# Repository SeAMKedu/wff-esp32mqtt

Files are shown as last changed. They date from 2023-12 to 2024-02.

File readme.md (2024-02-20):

[seamk_logo]:       /img/seamk_logo.svg
[epliitto_logo]:    /img/epliitto_logo.jpg
[eakr_eu_logo]:     /img/eakr_eu_logo.jpg



# Analogia signaalit pilveen

Ruokalaboratorion homogenisaattorissa on valmiit liitännät, joista voi lukea 4-20mA signaalin paineantureista. Tässä repositoryssä on kuvattu ESP32 pohjainen lähetin, joka osaa lukea nämä signaalit ja lähettää ne edelleen MQTT viesteinä eteenpäin. 

## Piirilevy

PCB kansiosta löytyy KiCAD piirustukset sovittimesta, johon voi laittaa ESP32 Dev Kitin kiinni sekä kytkeä 24V virran ja kaksi mA-signaalia. HUOM! Tämä on laajempaa jakelua varten piirretty uudelleen KiCADilla, eikä sitä ole testattu. Testattu prototyyppi tehtiin EasyEDAlla mikä on hieman rajattu yhteen piirilevyvalmistajaan. KiCAD versiossa on myös lisätty OneWire liitäntä lämpötila-anturia varten, mikä ei ole käytössä ohjelmassa.

## Ohjelma

Ohjelma ESP32:lle tietojen lähettämistä varten on kirjoitettu PlatformIO ympäristössä. Asenna se ja avaa projekti. `platformio.ini` tiedostossa on muuttujat WIFI-verkon ja MQTT palvelimen asetuksille. Aseta sinne itsellesi sopivat arvot.

## Wise Frami Food hanke

Tämä ohjelma luotiin osana Wise Frami Food hanketta, jossa rakennettiin piloitointiympäristö Frami Food Labin yhteyteen.

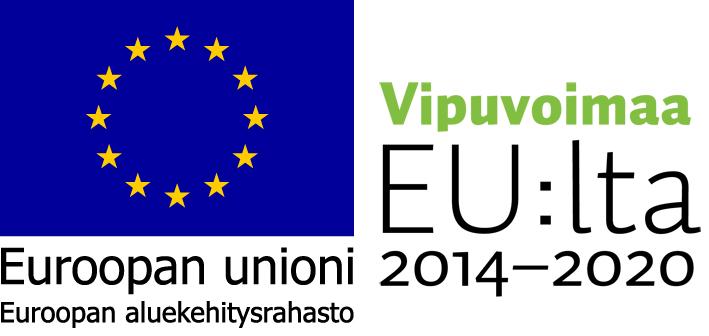
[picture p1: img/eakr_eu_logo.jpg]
eakr_eu_logo
 

---

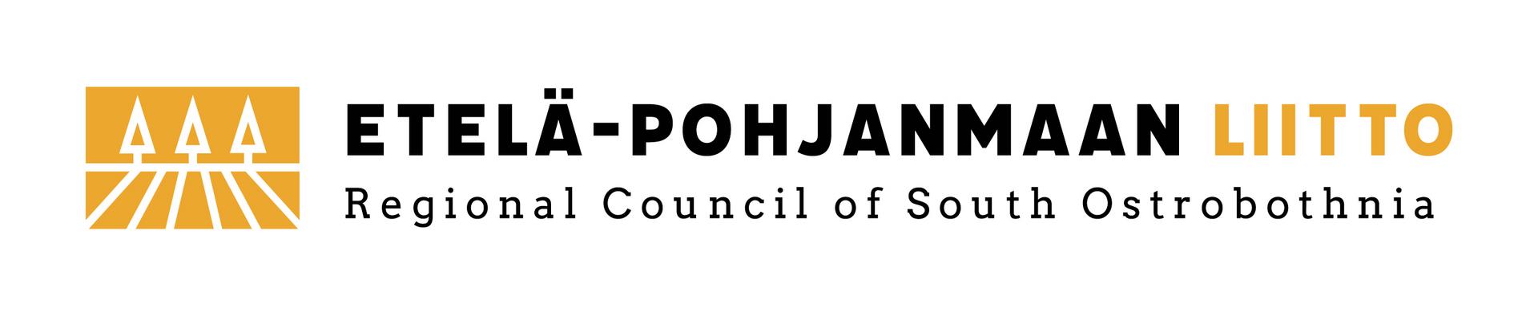
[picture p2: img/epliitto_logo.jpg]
epliitto_logo


---

seamk_logo

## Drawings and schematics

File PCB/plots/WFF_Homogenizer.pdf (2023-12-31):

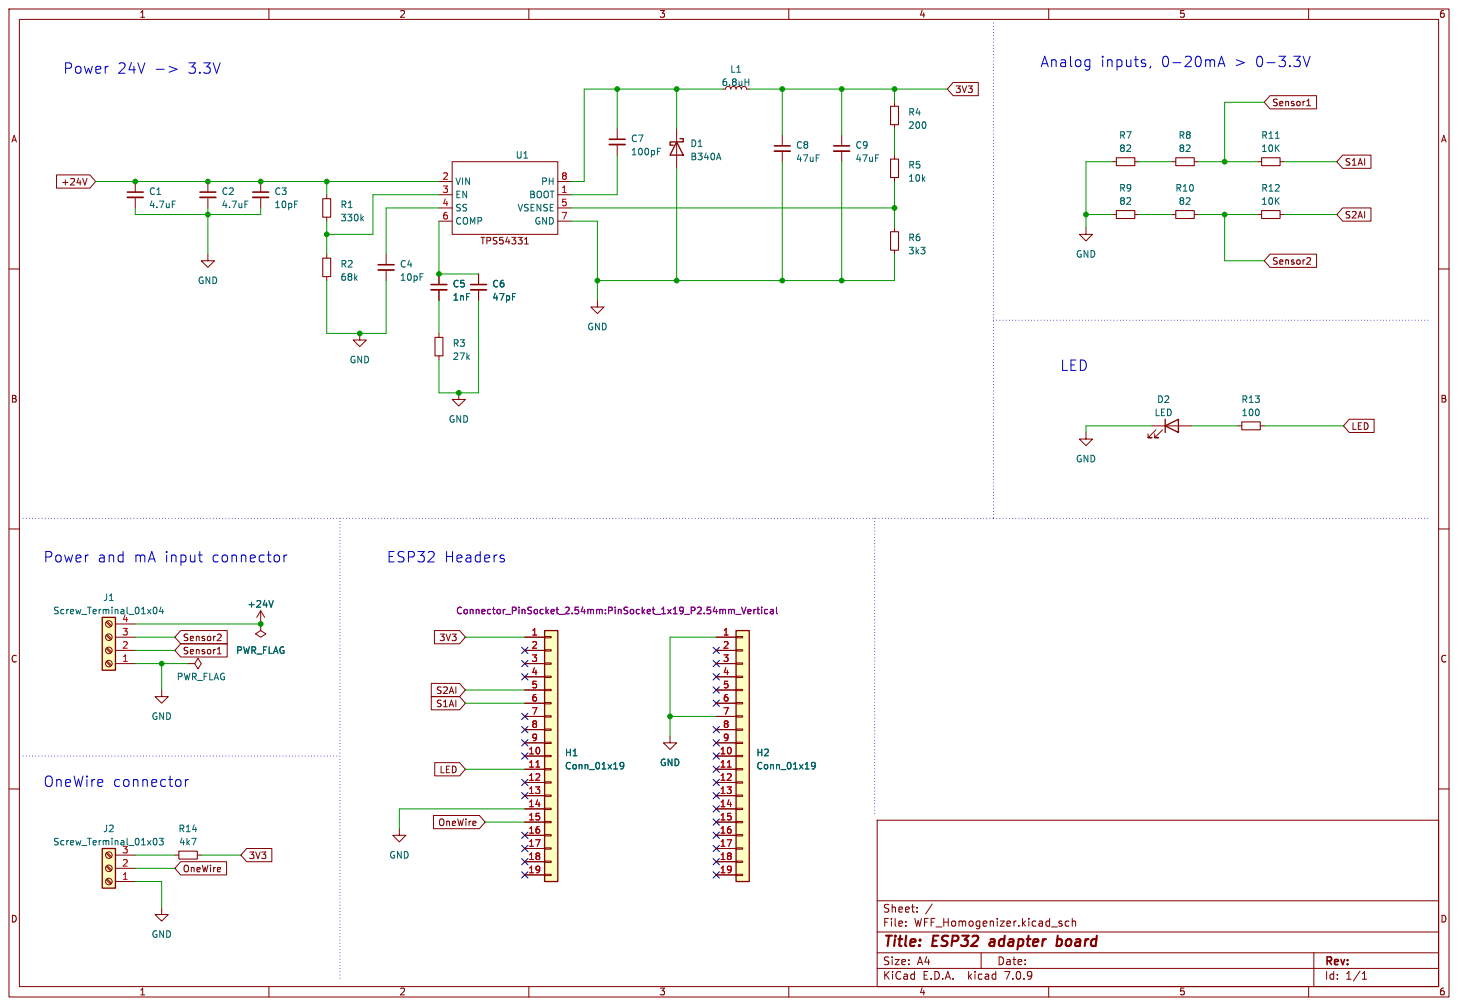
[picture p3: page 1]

Power and mA input connector

File: WFF_Homogenizer.kicad_sch Sheet: /
Id: 1/1 Title: ESP32 adapter board

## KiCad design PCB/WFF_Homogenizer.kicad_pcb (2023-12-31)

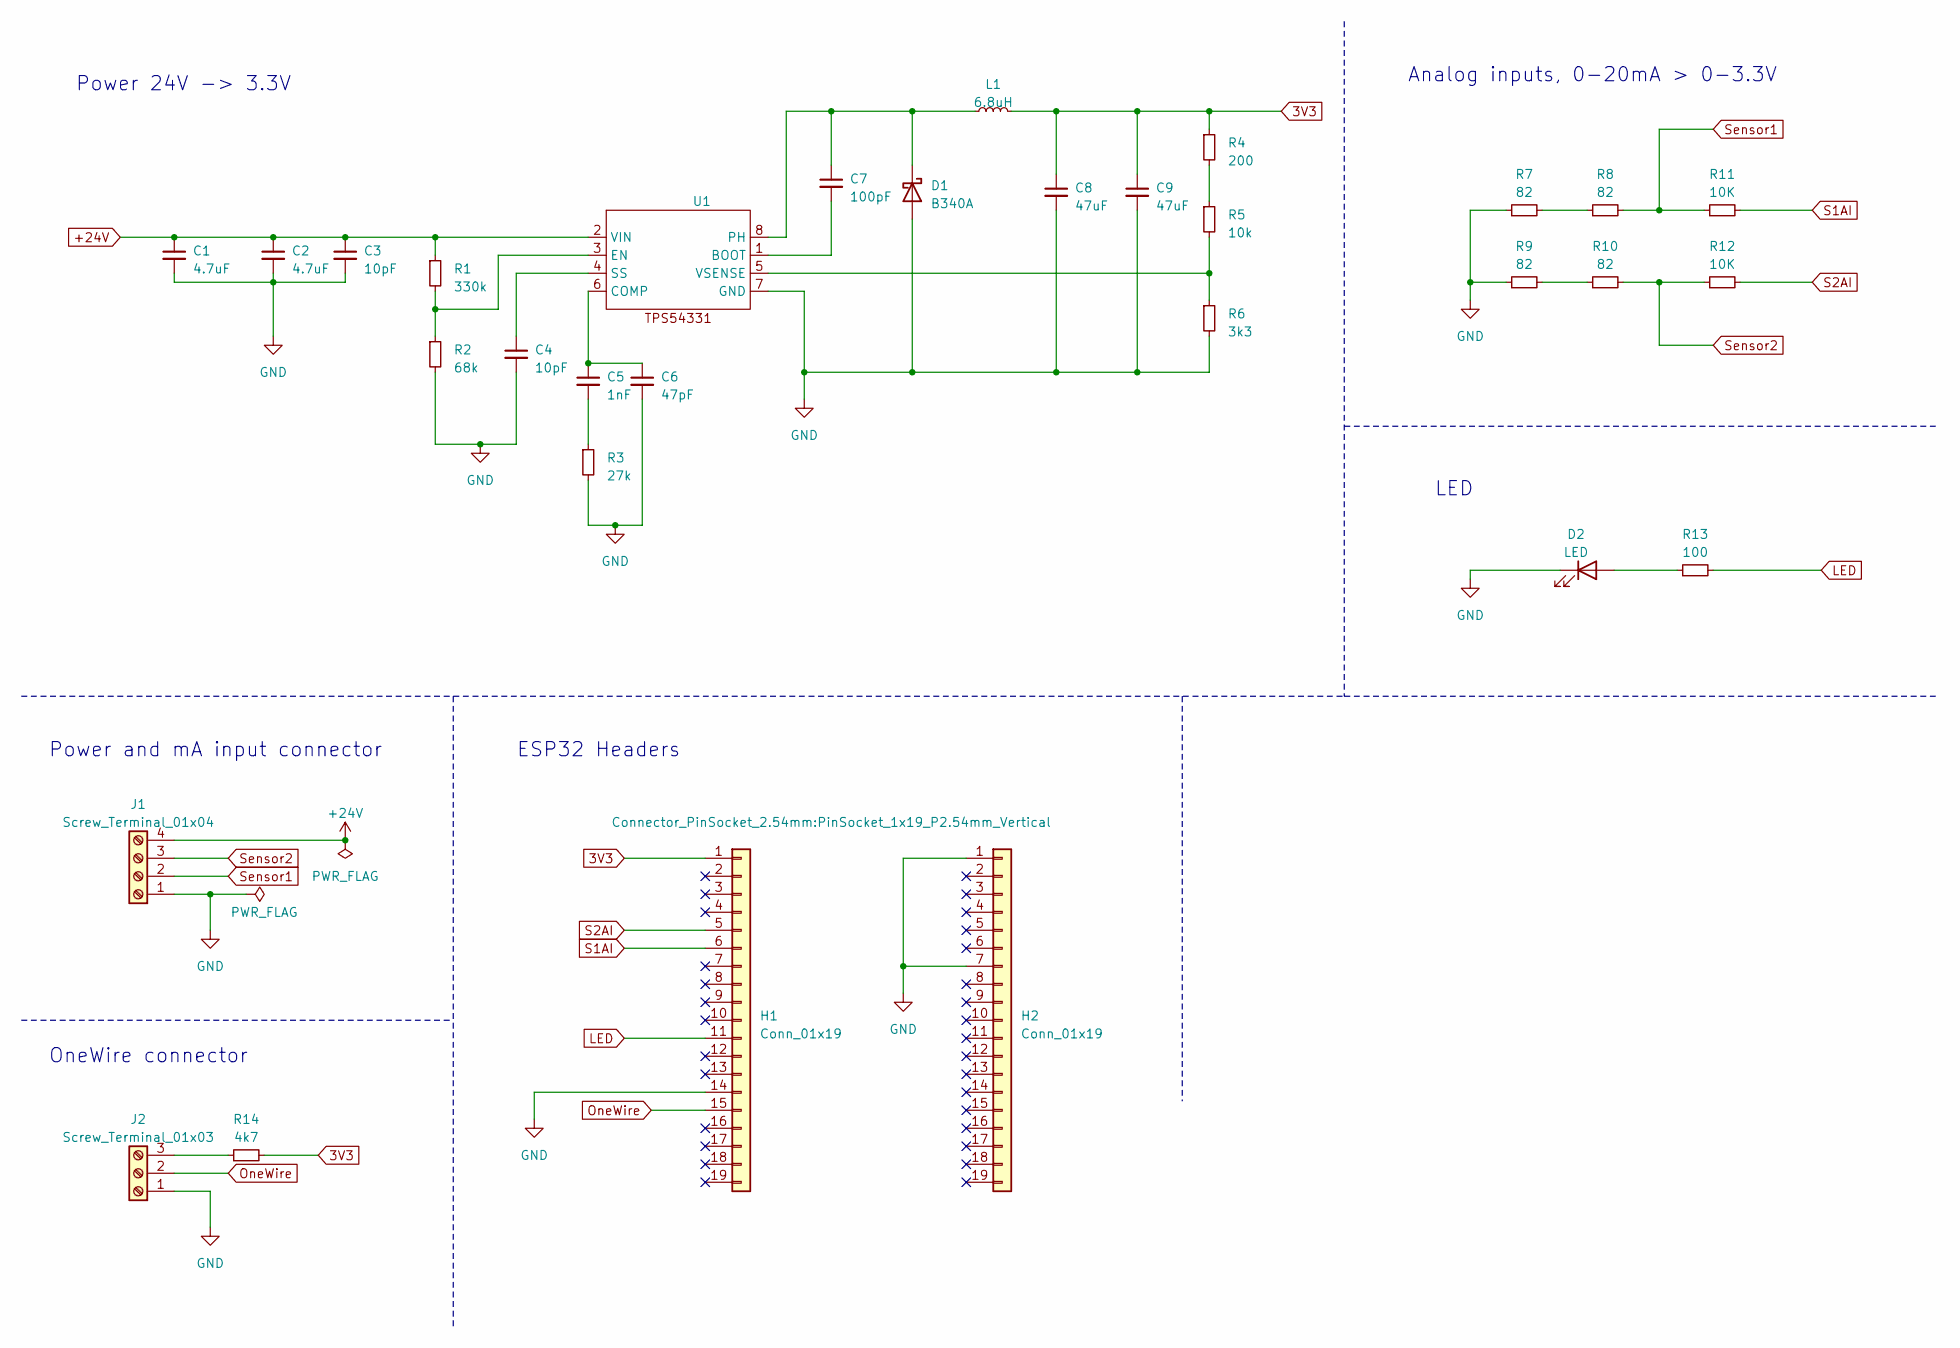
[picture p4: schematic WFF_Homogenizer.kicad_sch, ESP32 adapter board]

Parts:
C1, C2: 4.7uF; C_0603_1608Metric
C3, C4: 10pF; C_0603_1608Metric
C5: 1nF; C_0603_1608Metric
C6: 47pF; C_0603_1608Metric
C7: 100pF; C_0603_1608Metric
C8, C9: 47uF; C_0603_1608Metric
D1: B340A; D_SMA
D2: LED; LED_0603_1608Metric
H1, H2: Conn_01x19; PinSocket_1x19_P2.54mm_Vertical
J1: Screw_Terminal_01x04; TerminalBlock_Phoenix_MKDS-1,5-4_1x04_P5.00mm_Horizontal
J2: Screw_Terminal_01x03; TerminalBlock_Phoenix_MKDS-1,5-3_1x03_P5.00mm_Horizontal
L1: 6.8uH; L_6.3x6.3_H3
R1: 330k; R_0603_1608Metric
R2: 68k; R_0603_1608Metric
R3: 27k; R_0603_1608Metric
R4: 200; R_0603_1608Metric
R5: 10k; R_0603_1608Metric
R6: 3k3; R_0603_1608Metric
R7, R8, R9, R10: 82; R_0603_1608Metric
R11, R12: 10K; R_0603_1608Metric
R13: 100; R_0603_1608Metric
R14: 4k7; R_0603_1608Metric
U1: TPS54331DR SOIC-8

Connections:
3V3: C8.1, C9.1, H1.1, L1.2, R4.1, R14.2
+24V: C1.1, C2.1, C3.1, J1.4, R1.1, U1.2 (VIN)
GND: C1.2, C2.2, C3.2, C4.2, C6.2, C8.2, C9.2, D1.2 (A), D2.1 (K), H1.14, H2.1, H2.7, J1.1, J2.1, R2.2, R3.2, R6.2, R7.1, R9.1, U1.7 (GND)
LED: H1.11, R13.2
unnamed: C5.2, R3.1
unnamed: C7.1, D1.1 (K), L1.1, U1.8 (PH)
unnamed: D2.2 (A), R13.1
unnamed: J2.3, R14.1
unnamed: R4.2, R5.1
unnamed: R7.2, R8.1
unnamed: R9.2, R10.1
unnamed: C7.2, U1.1 (BOOT)
unnamed: C5.1, C6.1, U1.6 (COMP)
unnamed: R1.2, R2.1, U1.3 (EN)
unnamed: C4.1, U1.4 (SS)
unnamed: R5.2, R6.1, U1.5 (VSENSE)
OneWire: H1.15, J2.2
S1AI: H1.6, R11.2
S2AI: H1.5, R12.2
Sensor1: J1.2, R8.2, R11.1
Sensor2: J1.3, R10.2, R12.1

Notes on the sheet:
Analog inputs, 0-20mA > 0-3.3V
ESP32 Headers
Power and mA input connector
OneWire connector
LED
Power 24V -> 3.3V

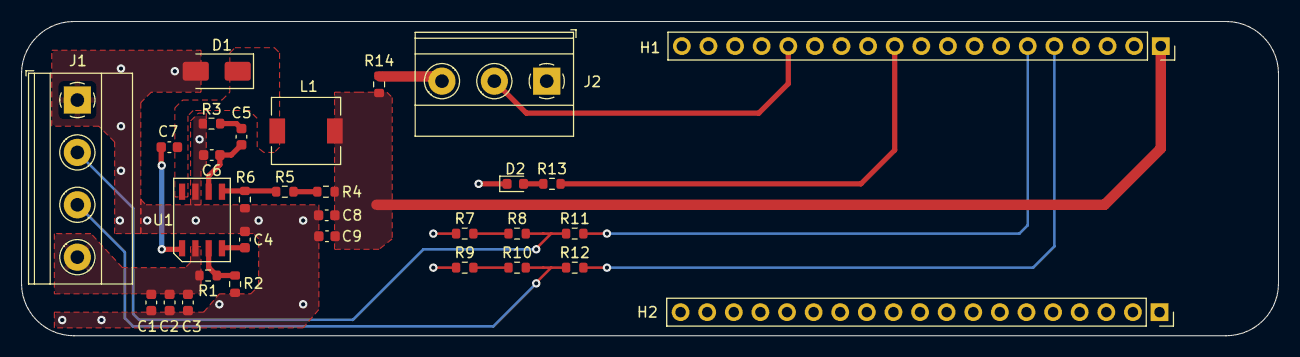
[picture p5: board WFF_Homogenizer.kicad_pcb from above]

Board: 2 copper layers, 120.0 x 30.0 mm, 31 parts (0 on the bottom side), 21 nets.

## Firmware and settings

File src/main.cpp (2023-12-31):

#include <Arduino.h>
#include <ArduinoJson.h>
#include <WiFi.h>
#include <PubSubClient.h>
#include <OneWire.h>
#include <DallasTemperature.h>

#define LED         27
#define AN_Sensor1  34
#define AN_Sensor2  35
#define ONEWIRE     25

// https://www.esp32.com/viewtopic.php?t=13053

uint8_t temprature_sens_read();
void setup_wifi();
void callback(char* topic, byte* message, unsigned int length);
void readAnalogValues();

const char* clientName = CLIENT_NAME;
const char* topicInput = TOPIC_INPUT;
const char* topicOutput = TOPIC_OUTPUT;
const char* ssid = WIFI_SSID;
const char* password = WIFI_PASSWORD;
const char* mqtt_server = MQTT_SERVER;
const char* mqtt_user = MQTT_USERNAME;
const char* mqtt_passwd = MQTT_PASSWORD;
const int adcAt4mA = ADC_AT4MA;
const int adcAt20mA = ADC_AT20MA;
const int sensorMin = ADC_MIN;                      // 0 bar
const int sensorMax = ADC_MAX;                   // 1000 bar
const uint8_t numReadings = 16;
const uint8_t numSensors = 4;
uint32_t readings[numSensors][numReadings];   // multi-dimensional readings from analog input
uint32_t readIndex = 0;                       // the index of the current reading
uint32_t total[numSensors] = {0};             // the running total
uint32_t average = 0;                         // the average

// interval to stabilize analog input smoothing readings
// ADC1 Channel read time ~9.5µs per sample --> 64 readings x 9.5 = 608 µs = .608 ms
uint8_t numReadingsInterval = 2;
uint32_t numReadingsStart = 0;

WiFiClient espClient;
PubSubClient client(espClient);

OneWire oneWire(ONEWIRE);
DallasTemperature sensors(&oneWire);
int numberOfDevices;
DeviceAddress tempDeviceAddress; 

long lastMsg = 0;
char msg[50];
int value = 0;
int sensor1value = 0;
int sensor2value = 0;
bool ledOn = false;

void setup() {
  Serial.begin(115200);

  pinMode(LED, OUTPUT);

  analogReadResolution(12);
  analogSetWidth(12);
  analogSetAttenuation(ADC_11db);
  adcAttachPin(AN_Sensor1);
  adcAttachPin(AN_Sensor2);

  // initialize all the readings to 0
  for (uint8_t thisReading = 0; thisReading < numReadings; thisReading++) {
    for ( uint8_t j = 0; j < numSensors; j++)  readings[j][thisReading] = 0;
  }

  setup_wifi();

  client.setServer(mqtt_server, 1883);
  client.setCallback(callback);

  numberOfDevices = sensors.getDeviceCount();
}

void setup_wifi() {
  delay(10);
  // We start by connecting to a WiFi network
  Serial.println();
  Serial.print("Connecting to ");
  Serial.println(ssid);

  WiFi.begin(ssid, password);

  while (WiFi.status() != WL_CONNECTED) {
    delay(500);
    Serial.print(".");

    if (ledOn) {
      digitalWrite (LED, LOW);
      ledOn = false;
    } else {
      digitalWrite (LED, HIGH);
      ledOn = true;
    }
  }

  digitalWrite (LED, HIGH);
  ledOn = true;

  Serial.println("");
  Serial.println("WiFi connected");
  Serial.print("IP address: ");
  Serial.println(WiFi.localIP());
}

void callback(char* topic, byte* message, unsigned int length) {
  Serial.print("Message arrived on topic: ");
  Serial.print(topic);
  Serial.print(". Message: ");
  String messageTemp;
  
  for (int i = 0; i < length; i++) {
    Serial.print((char)message[i]);
    messageTemp += (char)message[i];
  }
  Serial.println();
}

void reconnect() {
  // Loop until we're reconnected
  while (!client.connected()) {
    digitalWrite (LED, HIGH);
    Serial.print("Attempting MQTT connection...");
    // Attempt to connect
    if (client.connect(clientName, mqtt_user, mqtt_passwd)) {
    //if (client.connect(clientName)) {
      Serial.println("connected");
      digitalWrite (LED, LOW);
      // Subscribe
      client.subscribe(topicInput);
    } else {
      Serial.print("failed, rc=");
      Serial.print(client.state());
      Serial.println(" try again in 5 seconds");
      // Wait 5 seconds before retrying
      delay(5000);
    }
  }
}

void readAnalogValues() {
  // Read the sensor
  uint16_t sensor1 = analogRead(AN_Sensor1);
  uint16_t sensor2 = analogRead(AN_Sensor2);
  uint16_t inputPin[numSensors] = { sensor1, sensor2 };

  for (uint8_t ai = 0; ai < numSensors ; ai++) {
    total[ai] = total[ai] - readings[ai][readIndex];  // remove previous value from total
    readings[ai][readIndex] = inputPin[ai];           // store current value
    total[ai] = total[ai] + readings[ai][readIndex];  // add current to total
  }

  // advance index or loop around
  readIndex = readIndex + 1;
  if (readIndex >= numReadings) {
    readIndex = 0;
  }

  // calculate average from total
  sensor1value = total[0] / numReadings;
  sensor2value = total[1] / numReadings;
}

void loop() {
  if (!client.connected()) {
    reconnect();
  }

  client.loop();

  int hall = hallRead();
  // temperature sensor is not present
  //float temp = (temperatureRead() - 32 ) / 1.8;
  
  if (millis() - numReadingsStart >= numReadingsInterval * numReadings) {
    numReadingsStart = millis();
    readAnalogValues();
  }

  long now = millis();
  if (now - lastMsg >= 1000) {
    // led is on every other second
    ledOn = !ledOn;

    if (ledOn) {
      digitalWrite (LED, HIGH);
    } else {
      digitalWrite (LED, LOW);
    }

    //Serial.println("Temp: " + String(temp) + "C, hall: " + String(hall) + "C, S1: " + String(sensor1value) + "V, S2: " + String(sensor2value) + "V");
    //Serial.println("Hall: " + String(hall) + "C, S1: " + String(sensor1value) + ", " + String(sensor1Pressure) + " bar, S2: " + String(sensor2value) + ", " + String(sensor1Pressure) + " bar, [" + String(adcAt4mA) + ", " + String(adcAt20mA) + "]");

    lastMsg = now;
    //char tempString[8];
    //dtostrf(temp, 1, 2, tempString);

    char sensor1rawString[8];
    dtostrf(sensor1value, 1, 2, sensor1rawString);

    char sensor2rawString[8];
    dtostrf(sensor2value, 1, 2, sensor2rawString);

    char hallString[8];
    dtostrf(hall, 1, 2, hallString);

    DynamicJsonDocument json(300);
    
    json["hall"] = hallString;
    json["s1raw"] = sensor1rawString;
    json["s2raw"] = sensor2rawString;
 
    sensors.requestTemperatures();
    for(int i=0; i < numberOfDevices; i++) {
      if (sensors.getAddress(tempDeviceAddress, i)) {
        //float tempC = sensors.getTempC(tempDeviceAddress);
        json["temp" + i] = sensors.getTempC(tempDeviceAddress);
      }
    }

    char buffer[100];
    size_t n = serializeJson(json, buffer);
    
    if (client.publish(topicOutput, buffer, n) != true) {
      Serial.println("Error sending message");
    }
  }

  // no need to run too fast
  delay(50);
}
